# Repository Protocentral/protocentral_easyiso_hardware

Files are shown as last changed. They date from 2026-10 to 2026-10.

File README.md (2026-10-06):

ProtoCentral easyISO — Isolated Qwiic Adapter
==============================================

easyISO galvanically isolates a Qwiic / STEMMA QT I²C link — data and power — so a body-connected
sensor never shares a ground with a mains-powered computer.

* **I²C isolator:** TI ISO1640 (8-pin SOIC), bidirectional SDA/SCL, hot-swappable, up to 1.7 MHz
* **Isolated power:** MPS MIE1W0505BGLVH isolated DC-DC module, 3.3 V out (about 75 mA)
* **Connectors:** one Qwiic port and one 0.1" 4-pin header (SCL, SDA, VCC, GND) on each side
* **Pull-ups:** 10 kΩ on SDA and SCL, on both sides
* **Board:** 33 × 18.7 mm, 2-layer, 4 × M2 mounting holes

The voltage ratings above are the manufacturers' component ratings. easyISO is a development tool,
not a certified medical isolation barrier.

Repository contents
-------------------
* **/hardware** — KiCad project (`easyISO.kicad_pro`, `.kicad_sch`, `.kicad_pcb`) and the schematic
  PDF (`pc_easyiso_v1_schematic.pdf`)

Revisions
---------
| Revision | Date | Notes |
|---|---|---|
| v1 | 2026-08 | First release |

License Information
===================

Hardware
--------
**All hardware is released under the [CERN-OHL-P v2](https://ohwr.org/cern_ohl_p_v2.txt)** license.

This source describes Open Hardware and is licensed under the CERN-OHL-P v2.

You may redistribute and modify this documentation and make products using it under the terms of
the CERN-OHL-P v2 (https://cern.ch/cern-ohl). This documentation is distributed WITHOUT ANY EXPRESS
OR IMPLIED WARRANTY, INCLUDING OF MERCHANTABILITY, SATISFACTORY QUALITY AND FITNESS FOR A
PARTICULAR PURPOSE. Please see the CERN-OHL-P v2 for applicable conditions.

Documentation
-------------
**All documentation is released under [Creative Commons Share-alike 4.0 International](http://creativecommons.org/licenses/by-sa/4.0/).**

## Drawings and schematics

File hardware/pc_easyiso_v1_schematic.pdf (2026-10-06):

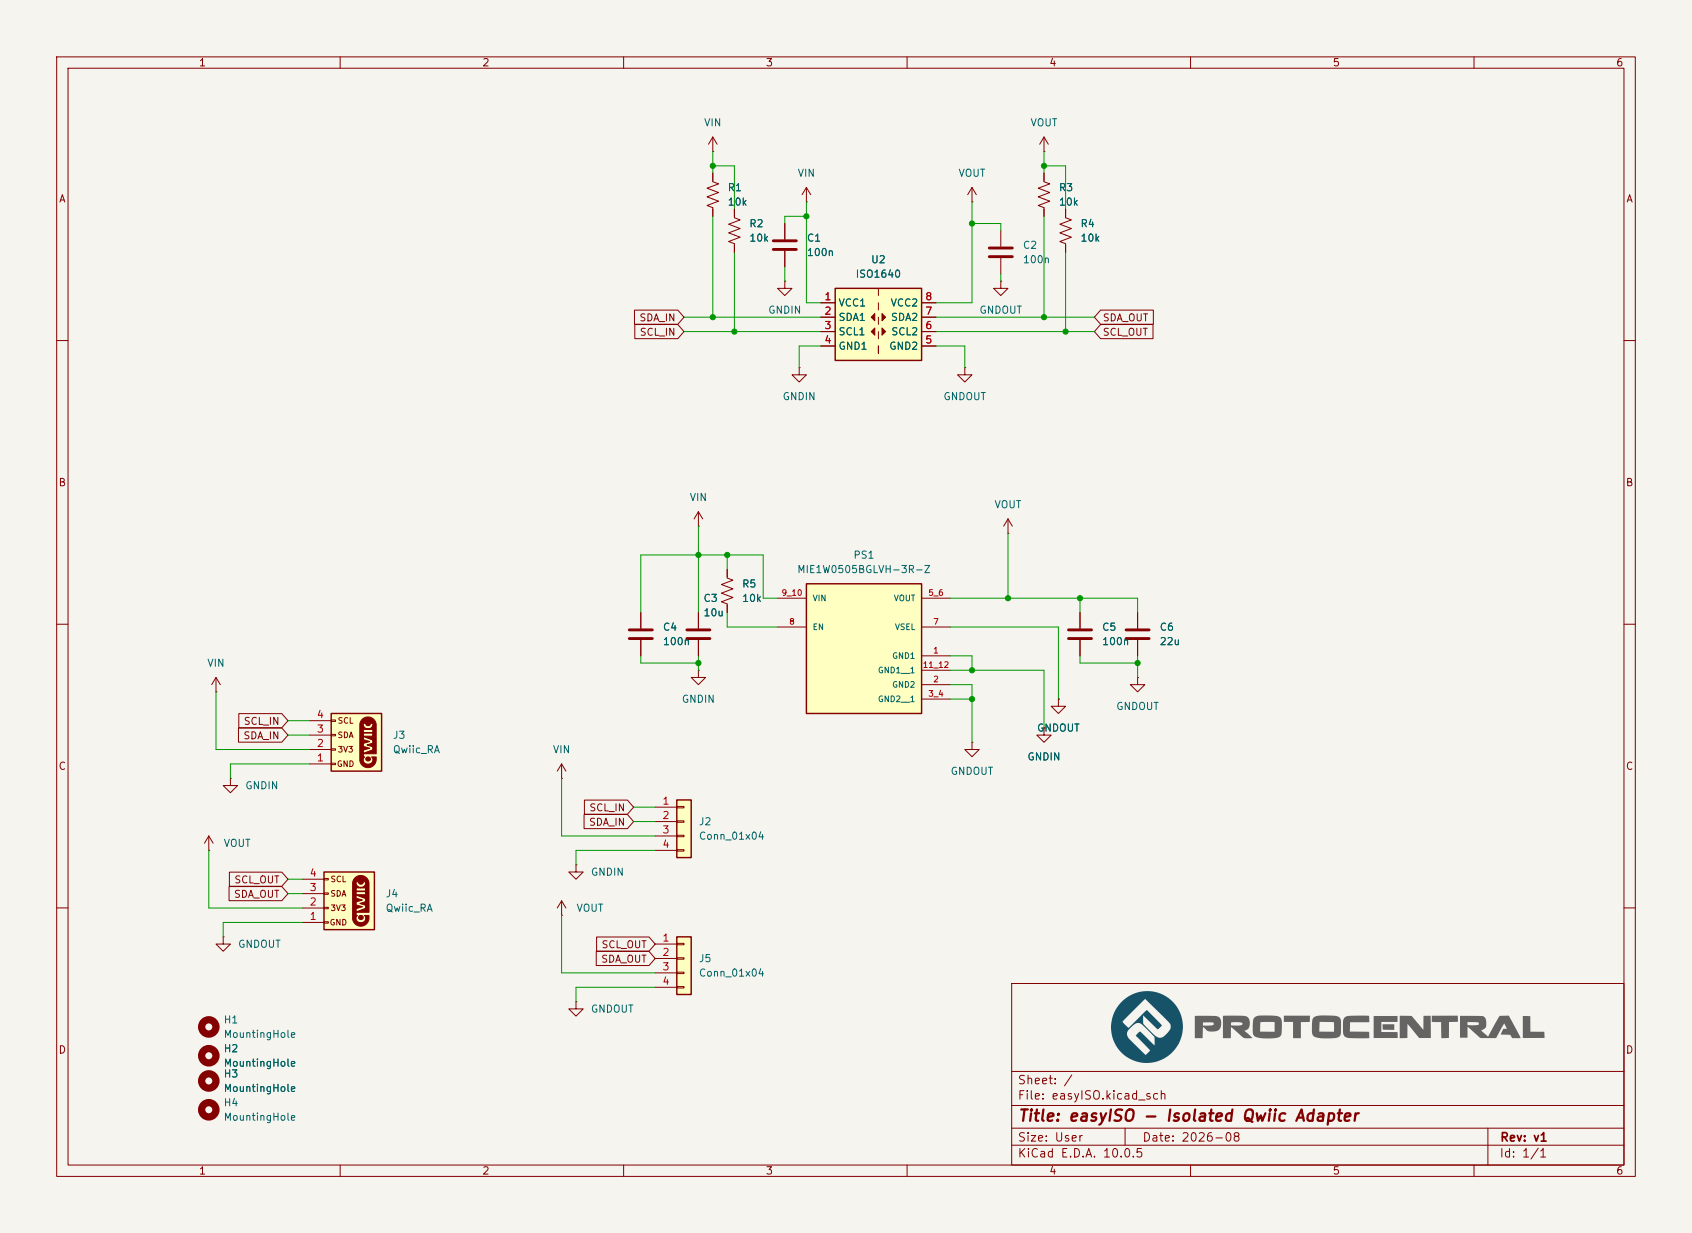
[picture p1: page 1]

Sheet: /
File: easyISO.kicad_sch
Title: easyISO - Isolated Qwiic Adapter

Size: User | Rev: v1
KiCad E.D.A. 10.0.5 | Id: 1/1

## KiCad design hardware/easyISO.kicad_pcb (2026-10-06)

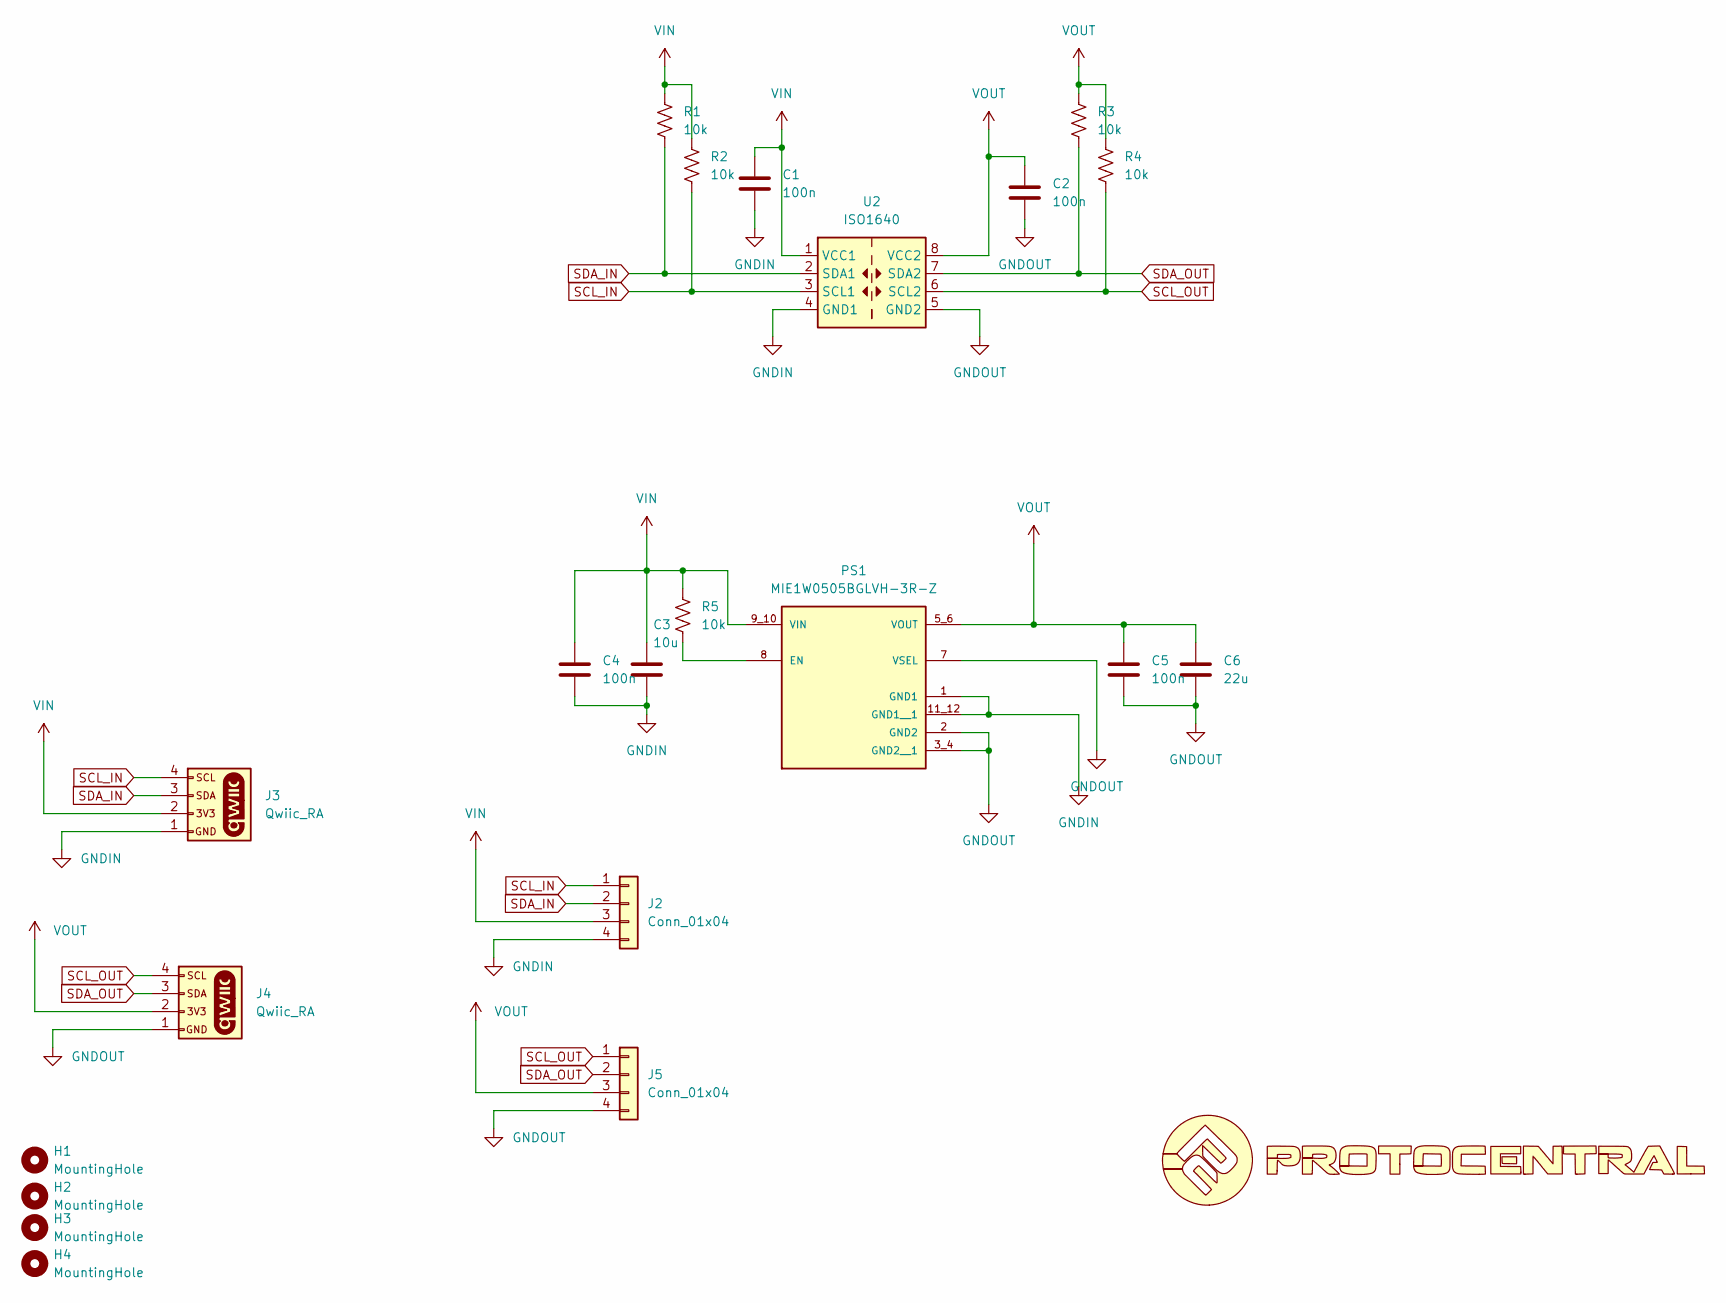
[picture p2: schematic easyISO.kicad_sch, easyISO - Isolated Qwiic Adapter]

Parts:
C1, C2, C4, C5: 100n; C_0402_1005Metric
C3: 10u; C_0805_2012Metric
C6: 22u; C_0805_2012Metric
H1, H2, H3, H4: MountingHole; MountingHole_2.2mm_M2
J2, J5: Conn_01x04; PinHeader_1x04_P2.54mm_Vertical
J3, J4: Qwiic_RA; JST_SH_SM04B-SRSS-TB_1x04-1MP_P1.00mm_Horizontal
PS1: MIE1W0505BGLVH-3R-Z; CONV_MIE1W0505BGLVH-3R-Z; PARTREV 0.8
R1, R2, R3, R4, R5: 10k; R_0402_1005Metric
U1: LOGO
U2: ISO1640; SOIC-8_3.9x4.9mm_P1.27mm

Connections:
GNDIN: C1.2, C3.2, C4.2, J2.4, J3.1, PS1.1 (GND1), PS1.11_12 (GND1__1), U2.4 (GND1)
GNDOUT: C2.2, C5.2, C6.2, J4.1, J5.4, PS1.2 (GND2), PS1.3_4 (GND2__1), PS1.7 (VSEL), U2.5 (GND2)
unnamed: PS1.8 (EN), R5.2
SCL_IN: J2.1, J3.4, R2.2, U2.3 (SCL1)
SCL_OUT: J4.4, J5.1, R4.2, U2.6 (SCL2)
SDA_IN: J2.2, J3.3, R1.2, U2.2 (SDA1)
SDA_OUT: J4.3, J5.2, R3.2, U2.7 (SDA2)
VIN: C1.1, C3.1, C4.1, J2.3, J3.2, PS1.9_10 (VIN), R1.1, R2.1, R5.1, U2.1 (VCC1)
VOUT: C2.1, C5.1, C6.1, J4.2, J5.3, PS1.5_6 (VOUT), R3.1, R4.1, U2.8 (VCC2)

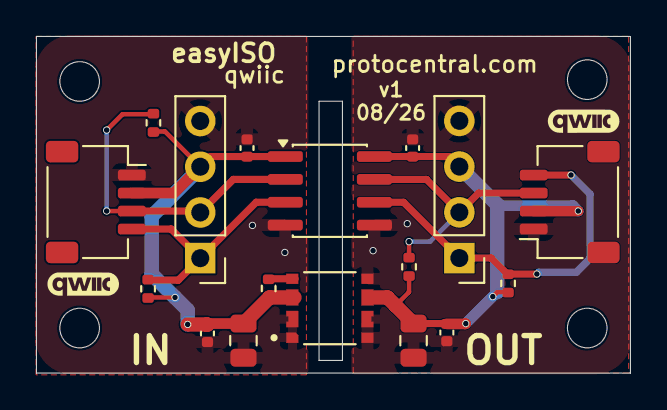
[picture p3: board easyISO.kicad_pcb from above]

Board: 2 copper layers, 33.0 x 18.7 mm, 21 parts (0 on the bottom side), 9 nets.
